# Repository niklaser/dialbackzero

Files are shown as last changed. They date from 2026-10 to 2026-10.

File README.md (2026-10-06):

# Dialback Zero

Dialback Zero lets an old computer get online through its serial port.
It works like a dial-up modem, but connects over Ethernet or Wi-Fi instead of
a phone line.

## Get started

1. [Assemble the board](docs/assembly.md) using the [parts list](docs/self-solder-parts.md).
2. [Print and assemble the enclosure](enclosure/README.md).
3. [Download the Raspberry Pi image](image/README.md) and write it to a microSD card.
4. [Connect your computer and make the first call](docs/setup.md).

Use a straight-through RS-232 cable and **38400 baud, 8N1, flow control off**.
The Rev C serial port supports TX, RX and GND.

| Connection | Dial number | Settings page |
|---|---|---|
| Internet | `2242525` | `http://172.16.0.1/`  |
| Private server | `777` | `http://172.16.77.1/` |

## Files and guides

- [PCB manufacturing files](manufacturing/rev-c/README.md)
- [Ready-to-print STL files](enclosure/README.md)
- [Software settings](software/README.md)
- [Private server with Docker Compose](server/README.md)
- [GPIO and connector reference](docs/hardware.md)
- [Licenses](LICENSES.md)

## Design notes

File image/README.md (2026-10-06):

# Raspberry Pi image

Raspberry Pi OS Lite 32-bit for Pi Zero, Zero W/WH and Zero 2 W, with
Dialback Zero preinstalled.

## Download from GitHub

1. Download an image from **Releases**, or open **Actions → Test and build
   Raspberry Pi image and update** and download the artifact from a successful run.
2. Extract the artifact ZIP if needed, then select the `.img.xz` in Raspberry
   Pi Imager using **Use custom**.
3. Set your user account, network and locale, then write the microSD card.
   Enable SSH in Imager if you want remote access.
4. Insert the card into the Pi and power it on. Continue with the
   [setup guide](../docs/setup.md).

After setup, use **Check for updates** and **Install update** on the settings
page. These update Dialback Zero software and preserve your settings; they do
not replace Raspberry Pi OS or require writing the card again.

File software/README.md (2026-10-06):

# Dialback Zero software

The modem, settings page, PPP and status lights start automatically at boot.
Use the [image guide](../image/README.md) and [first-boot guide](../docs/setup.md)
to get started. The optional [server](../server/README.md) provides the private
network reached by dialing `777`.

## Settings

Open `http://172.16.0.1/` over Internet PPP, `http://172.16.77.1/` over private
PPP, or `http://localhost/` on the Pi. Use `AT$CONFIG` for serial settings while
disconnected. The web page requires no JavaScript.

Settings take effect after a restart.

Speaker volume is 0–100% (default 70%); zero mutes it. `ATM1` enables dialing
sounds and `ATM0` disables them. Leave the board's MUTE jumper open for sound.
Configure Wi-Fi in Raspberry Pi Imager or on the settings page.

## Update

On the settings page, select **Check for updates**, then **Install update**.
Installation disconnects the current call; reconnect afterward and open settings
to see the result. Updates preserve your settings and update Dialback Zero
software only, not Raspberry Pi OS or the microSD image.

## Diagnostics

```sh
systemctl status dialback-zero.target dialback-zero-modem.service
journalctl -u dialback-zero-modem.service -b
sudo wg show wg-dbz latest-handshakes
```

See [LED meanings and GPIOs](../docs/hardware.md) and [licenses](../LICENSES.md).

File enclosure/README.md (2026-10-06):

# Enclosure

## Print

Download these files and import them into your slicer at **100% scale**:

| File | Quantity | Print orientation |
|---|---:|---|
| [Base](dialback-zero-base.stl) | 1 | Floor down |
| [Lid](dialback-zero-lid.stl) | 1 | Roof down |
| [Power-button cap](power-button-cap.stl) | 1 | On its flange |
| [12 mm Pi spacer](pi-spacer-12mm.stl) | 4 | Vertical |

Use **a 0.4 mm nozzle, 0.2 mm layers and four perimeters**.

Also needed: **two M3 x 25 screws** and
**two M3 hex nuts**.

## Assemble

1. Fit the Pi's male header on its component side and the board's J1 female
   socket on the underside. Use the sockets in the [parts list](../docs/self-solder-parts.md).
2. Place the Pi on the base guide pins. Slide a printed spacer onto each pin.
3. Align J1 with the Pi header and press the board down evenly onto its supports.
4. Insert the button cap from inside the lid with its flange wings vertical.
   Rotate it 90° so the power symbol is upright, and check it moves freely.
5. Slide the two nuts into the lid pockets. Lower the lid over the connectors,
   keeping the cap aligned with the power switch.
6. Insert both screws from below and tighten lightly until the case closes.

Remove both screws to open the case. The screws do not pass through either board.

STL files: **CC0-1.0**.

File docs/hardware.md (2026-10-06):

# Rev C hardware reference

The PCB is 130 × 80 mm. J1, the Pi socket, mounts underneath; all other parts
mount on top. See [assembly](assembly.md), [hand-soldered parts](self-solder-parts.md)
and [enclosure](../enclosure/README.md).

| Function | BCM GPIO | Physical header pin |
| --- | ---: | ---: |
| UART transmit to RS-232 driver | 14 | 8 |
| UART receive from RS-232 driver | 15 | 10 |
| Mono PWM audio | 12 | 32 |
| Reserved second audio output, not connected | 13 | 33 |
| Power-button interrupt, active low | 3 | 5 |
| Final shutdown power cut, active high | 26 | 37 |
| W5500 MOSI / MISO / clock / chip select | 10 / 9 / 11 / 8 | 19 / 21 / 23 / 24 |
| W5500 interrupt | 4 | 7 |
| MR / NET / SD / RD / CD / OH / AA lights | 23 / 25 / 22 / 27 / 24 / 5 / 6 | 16 / 22 / 15 / 13 / 18 / 29 / 31 |

PWR follows the switched 5 V rail. The other lights are active high: MR means
modem ready, NET means an upstream IPv4 address, SD/RD show data from/to the
computer, CD means connected, OH means off-hook and AA means auto-answer.

DE9 J2 uses pin 2 for RS-232 output, pin 3 for input and pin 5 for ground.
Other signal pins are unconnected; shield mounts are grounded.
Use a **straight-through cable with flow control off**.

The [hardware installer](../software/hardware/install.py) configures UART,
audio, shutdown and Ethernet. LED software must use only the listed LED GPIOs;
power, UART and Ethernet pins belong to kernel drivers.

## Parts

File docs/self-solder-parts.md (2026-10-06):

# Hand-soldered parts for Rev C

Buy 15 parts. **J1 mounts underneath** the carrier; all other parts mount on top.
USB-C J4 is factory fitted. Follow the [assembly guide](assembly.md).

| References | Qty | Part | Notes |
| --- | ---: | --- | --- |
| D1–D8 | 8 | Kingbright [WP934CB/GD](https://www.kingbrightusa.com/images/catalog/spec/wp934cb-gd.pdf) green or [WP934CB/YD](https://www.kingbrightusa.com/images/catalog/spec/wp934cb-yd.pdf) yellow | Right-angle LEDs; follow polarity markings |
| C17 | 1 | Panasonic EEU-FR1A221 | 220 µF, 10 V, 6.3 mm body, 2.5 mm lead pitch; follow polarity markings |
| J1 | 1 | [Samtec SSQ-120-01-G-D](https://suddendocs.samtec.com/catalog_english/ssq_th.pdf) or [Würth 61304021821](https://www.we-online.com/components/products/datasheet/61304021821.pdf) | Bottom-side 2 × 20 Pi socket |
| J2 | 1 | [Assmann A-DF 09 A/KG-T2S](https://www.assmann-wsw.com/uploads/pcn/PCN%2020120913-A-DX%20XX%20A_KG-T2_T4-rev0.pdf) or [Amphenol L77SDE09SA4CH4F48](https://cdn.amphenol-cs.com/media/wysiwyg/files/drawing/l77sdxxxsa4ch4f48.pdf) | Right-angle female DE9 with board locks and 4-40 hardware |
| J3 | 1 | Würth 61300211121 | 2.54 mm, 1 × 2 MUTE header |
| J5 | 1 | [Würth 7499010121A](https://www.we-online.com/components/products/datasheet/7499010121A.pdf) | Horizontal RJ45 with integrated magnetics |
| LS1 | 1 | [PUI Audio AST-02308MR-R](https://puiaudio.com/file/specs-AST-02308MR-R.pdf) | 8-ohm magnetic speaker, not a piezo sounder |
| SW1 | 1 | C&K PTS645VL39-2 LFS | Right-angle momentary power button |

A 2.54 mm jumper for J3 is optional: fitted mutes the speaker; open enables it.

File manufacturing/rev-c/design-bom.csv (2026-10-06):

Reference | Value | Footprint | MPN | Manufacturer | Datasheet | FactoryAssembly | Notes
J1 | Pi Zero / Zero 2 W | DialbackZero:PinSocket_Samtec_SSQ-120-01-G-D | SSQ-120-01-G-D | Samtec Inc. | https://www.samtec.com/products/ssq-120-01-g-d | no | USER SOLDER AFTER DELIVERY; DNP for factory assembly. Female socket on BOTTOM; Pi below carrier with component-side 2x20 2.54mm male header; Existing exact MPN. 2x20 female receptacle, 2.54 mm pitch; mounted on PCB bottom. Manufacturer product page contains print/catalog and footprint downloads.
U1 | MAX3232EIDR | DialbackZero:SOIC-16_3.9x9.9mm_P1.27mm | MAX3232EIDR | Texas Instruments | https://www.ti.com/lit/ds/symlink/max3232e.pdf | yes | ; Authorized replacement of obsolete MAX3232IDR; SOIC-16. C1-C4 remain 100 nF at 3.3 V; C5 changed to 2.2 uF. TI requires >=1 uF VCC bypass for stated IEC ESD ratings; assembly/device-level ESD validation still required.
J2 | A-DF 09 A/KG-T2S | DialbackZero:DSUB9_Assmann_A-DF09A_KG-T2S | A-DF 09 A/KG-T2S | Assmann WSW Components | https://www.assmann-wsw.com/uploads/datasheets/ASS_4888_CO.pdf | yes | ASSMANN female DE9 DCE, 2.77x2.84mm, grounded shell boardlocks; see mechanical.md; Authorized replacement of A-DF 09 A/KG-T2. Mechanical review confirmed same PCB geometry. Female right-angle DE9, 8.10 mm backset, board locks, 4-40 screwlocks. DigiKey AE10921-ND.
C1 | 100n | DialbackZero:C_0805_2012Metric_Pad1.18x1.45mm_HandSolder | CC0805KRX7R9BB104 | YAGEO | https://yageogroup.com/content/datasheet/asset/file/UPY-GPHC_X7R_6_3V-TO-250V | yes | X7R 16V; 0805, 0.1 uF, X7R, ±10%, 50 V. Capacitance value preserved; voltage rating meets or exceeds design requirement.
C2 | 100n | DialbackZero:C_0805_2012Metric_Pad1.18x1.45mm_HandSolder | CC0805KRX7R9BB104 | YAGEO | https://yageogroup.com/content/datasheet/asset/file/UPY-GPHC_X7R_6_3V-TO-250V | yes | X7R 16V; 0805, 0.1 uF, X7R, ±10%, 50 V. Capacitance value preserved; voltage rating meets or exceeds design requirement.
C3 | 100n | DialbackZero:C_0805_2012Metric_Pad1.18x1.45mm_HandSolder | CC0805KRX7R9BB104 | YAGEO | https://yageogroup.com/content/datasheet/asset/file/UPY-GPHC_X7R_6_3V-TO-250V | yes | X7R 16V; 0805, 0.1 uF, X7R, ±10%, 50 V. Capacitance value preserved; voltage rating meets or exceeds design requirement.
C4 | 100n | DialbackZero:C_0805_2012Metric_Pad1.18x1.45mm_HandSolder | CC0805KRX7R9BB104 | YAGEO | https://yageogroup.com/content/datasheet/asset/file/UPY-GPHC_X7R_6_3V-TO-250V | yes | X7R 16V; 0805, 0.1 uF, X7R, ±10%, 50 V. Capacitance value preserved; voltage rating meets or exceeds design requirement.
C5 | 2.2u | DialbackZero:C_0805_2012Metric_Pad1.18x1.45mm_HandSolder | GRM21BR71C225KA12L | Murata Electronics | https://search.murata.co.jp/Ceramy/image/img/A01X/G101/ENG/GRM21BR71C225KA12-01A.pdf | yes | X7R 16V; Authorized change from 100 nF to 2.2 uF for MAX3232EIDR VCC bypass. 0805 X7R ±10% 16 V. Current Murata reference sheet fetched 2026-09-22 is dated 2026-06-25. Murata typical DC-bias chart (2013-03-08 manufacturer document, Octopart mirror, page 2) was visually inspected: loss at 3.3 V is only a few percent, conservatively <10%, giving about 2.1 uF typical. Applying an illustrative 10% bias loss, -10% nominal tolerance and -15% temperature change gives 1.51 uF. This is engineering margin based on a typical curve, not a guaranteed minimum across aging/lot/temperature or IEC ESD certification.
R1 | 2.2k | DialbackZero:R_0805_2012Metric_Pad1.20x1.40mm_HandSolder | RC0805FR-072K2L | YAGEO | https://yageogroup.com/content/datasheet/asset/file/PYU-RC_GROUP_51_ROHS_L | yes | 0805, 1%, >=0.125W; 0805, 2200 ohm, ±1% tolerance, 0.125 W. Preserves circuit value.
D1 | PWR / WP934CB/GD | DialbackZero:LED_Kingbright_WP934CB_Horizontal | WP934CB/GD | Kingbright | https://www.kingbrightusa.com/images/catalog/spec/wp934cb-gd.pdf | yes | 3mm right-angle; housing flush to PCB; emission toward front; Existing exact MPN; 3 mm green right-angle LED housing and original mechanical footprint.
R2 | 1k | DialbackZero:R_0805_2012Metric_Pad1.20x1.40mm_HandSolder | RC0805FR-071KL | YAGEO | https://yageogroup.com/content/datasheet/asset/file/PYU-RC_GROUP_51_ROHS_L | yes | 0805, 1%, >=0.125W; 0805, 1000 ohm, ±1% tolerance, 0.125 W. Preserves circuit value.
D2 | MR / WP934CB/GD | DialbackZero:LED_Kingbright_WP934CB_Horizontal | WP934CB/GD | Kingbright | https://www.kingbrightusa.com/images/catalog/spec/wp934cb-gd.pdf | yes | 3mm right-angle; housing flush to PCB; emission toward front; Existing exact MPN; 3 mm green right-angle LED housing and original mechanical footprint.
R11 | 1k | DialbackZero:R_0805_2012Metric_Pad1.20x1.40mm_HandSolder | RC0805FR-071KL | YAGEO | https://yageogroup.com/content/datasheet/asset/file/PYU-RC_GROUP_51_ROHS_L | yes | 0805, 1%, >=0.125W; 0805, 1000 ohm, ±1% tolerance, 0.125 W. Preserves circuit value.
D3 | NET / WP934CB/GD | DialbackZero:LED_Kingbright_WP934CB_Horizontal | WP934CB/GD | Kingbright | https://www.kingbrightusa.com/images/catalog/spec/wp934cb-gd.pdf | yes | 3mm right-angle; housing flush to PCB; emission toward front; Existing exact MPN; 3 mm green right-angle LED housing and original mechanical footprint.
R12 | 1k | DialbackZero:R_0805_2012Metric_Pad1.20x1.40mm_HandSolder | RC0805FR-071KL | YAGEO | https://yageogroup.com/content/datasheet/asset/file/PYU-RC_GROUP_51_ROHS_L | yes | 0805, 1%, >=0.125W; 0805, 1000 ohm, ±1% tolerance, 0.125 W. Preserves circuit value.
D4 | SD / WP934CB/GD | DialbackZero:LED_Kingbright_WP934CB_Horizontal | WP934CB/GD | Kingbright | https://www.kingbrightusa.com/images/catalog/spec/wp934cb-gd.pdf | yes | 3mm right-angle; housing flush to PCB; emission toward front; Existing exact MPN; 3 mm green right-angle LED housing and original mechanical footprint.
R13 | 1k | DialbackZero:R_0805_2012Metric_Pad1.20x1.40mm_HandSolder | RC0805FR-071KL | YAGEO | https://yageogroup.com/content/datasheet/asset/file/PYU-RC_GROUP_51_ROHS_L | yes | 0805, 1%, >=0.125W; 0805, 1000 ohm, ±1% tolerance, 0.125 W. Preserves circuit value.
D5 | RD / WP934CB/GD | DialbackZero:LED_Kingbright_WP934CB_Horizontal | WP934CB/GD | Kingbright | https://www.kingbrightusa.com/images/catalog/spec/wp934cb-gd.pdf | yes | 3mm right-angle; housing flush to PCB; emission toward front; Existing exact MPN; 3 mm green right-angle LED housing and original mechanical footprint.
R14 | 1k | DialbackZero:R_0805_2012Metric_Pad1.20x1.40mm_HandSolder | RC0805FR-071KL | YAGEO | https://yageogroup.com/content/datasheet/asset/file/PYU-RC_GROUP_51_ROHS_L | yes | 0805, 1%, >=0.125W; 0805, 1000 ohm, ±1% tolerance, 0.125 W. Preserves circuit value.
D6 | CD / WP934CB/GD | DialbackZero:LED_Kingbright_WP934CB_Horizontal | WP934CB/GD | Kingbright | https://www.kingbrightusa.com/images/catalog/spec/wp934cb-gd.pdf | yes | 3mm right-angle; housing flush to PCB; emission toward front; Existing exact MPN; 3 mm green right-angle LED housing and original mechanical footprint.
R15 | 1k | DialbackZero:R_0805_2012Metric_Pad1.20x1.40mm_HandSolder | RC0805FR-071KL | YAGEO | https://yageogroup.com/content/datasheet/asset/file/PYU-RC_GROUP_51_ROHS_L | yes | 0805, 1%, >=0.125W; 0805, 1000 ohm, ±1% tolerance, 0.125 W. Preserves circuit value.
D7 | OH / WP934CB/GD | DialbackZero:LED_Kingbright_WP934CB_Horizontal | WP934CB/GD | Kingbright | https://www.kingbrightusa.com/images/catalog/spec/wp934cb-gd.pdf | yes | 3mm right-angle; housing flush to PCB; emission toward front; Existing exact MPN; 3 mm green right-angle LED housing and original mechanical footprint.
R16 | 1k | DialbackZero:R_0805_2012Metric_Pad1.20x1.40mm_HandSolder | RC0805FR-071KL | YAGEO | https://yageogroup.com/content/datasheet/asset/file/PYU-RC_GROUP_51_ROHS_L | yes | 0805, 1%, >=0.125W; 0805, 1000 ohm, ±1% tolerance, 0.125 W. Preserves circuit value.
D8 | AA / WP934CB/GD | DialbackZero:LED_Kingbright_WP934CB_Horizontal | WP934CB/GD | Kingbright | https://www.kingbrightusa.com/images/catalog/spec/wp934cb-gd.pdf | yes | 3mm right-angle; housing flush to PCB; emission toward front; Existing exact MPN; 3 mm green right-angle LED housing and original mechanical footprint.
J4 | USB4125-GF-A-0190 | DialbackZero:USB_C_Receptacle_GCT_USB4125-xx-x-0190_6P_TopMnt_Horizontal | USB4125-GF-A-0190 | GCT | https://gct.co/files/drawings/usb4125.pdf | yes | 5V/3A supply required; power only; Pi PWR IN internal; Existing exact MPN. USB-C power connector; LCSC minimum 1. Do not replace with visually similar USB-C footprint.
R17 | 5.1k | DialbackZero:R_0805_2012Metric_Pad1.20x1.40mm_HandSolder | RC0805FR-075K1L | YAGEO | https://yageogroup.com/content/datasheet/asset/file/PYU-RC_GROUP_51_ROHS_L | yes | 0805, 1%, >=0.125W; 0805, 5100 ohm, ±1% tolerance, 0.125 W. Preserves circuit value. Mouser Canada snapshot last week reported 44,735; this is the same exact MPN, not a replacement.
R18 | 5.1k | DialbackZero:R_0805_2012Metric_Pad1.20x1.40mm_HandSolder | RC0805FR-075K1L | YAGEO | https://yageogroup.com/content/datasheet/asset/file/PYU-RC_GROUP_51_ROHS_L | yes | 0805, 1%, >=0.125W; 0805, 5100 ohm, ±1% tolerance, 0.125 W. Preserves circuit value. Mouser Canada snapshot last week reported 44,735; this is the same exact MPN, not a replacement.
U3 | TPS259470LRPWR | DialbackZero:TPS259470_RPW_2x2mm | TPS259470LRPWR | Texas Instruments | https://www.ti.com/lit/ds/symlink/tps25947.pdf | yes | Latch-off eFuse, always-on reverse blocking; 2.33A nominal limit; Existing exact MPN; eFuse, 10-VQFN-HR 2x2 mm. Preserve L latch variant.
R19 | 26.1k | DialbackZero:R_0805_2012Metric_Pad1.20x1.40mm_HandSolder | RC0805FR-0726K1L | YAGEO | https://yageogroup.com/content/datasheet/asset/file/PYU-RC_GROUP_51_ROHS_L | yes | 1% UVLO upper; 0805, 26100 ohm, ±1% tolerance, 0.125 W. Preserves circuit value.
R20 | 10k | DialbackZero:R_0805_2012Metric_Pad1.20x1.40mm_HandSolder | RC0805FR-0710KL | YAGEO | https://yageogroup.com/content/datasheet/asset/file/PYU-RC_GROUP_51_ROHS_L | yes | 1% UVLO lower; 0805, 10000 ohm, ±1% tolerance, 0.125 W. Preserves circuit value.
R21 | 34.8k | DialbackZero:R_0805_2012Metric_Pad1.20x1.40mm_HandSolder | RT0805BRD0734K8L | YAGEO | https://yageogroup.com/content/datasheet/asset/file/PYU-RT_1-TO-0-01_ROHS_L | yes | 0.1% OVLO upper; do not substitute 1%; 0805, 34800 ohm, ±0.1% tolerance, 0.125 W. Required 0.1% eFuse threshold divider part; do not substitute 1%.
R22 | 10k | DialbackZero:R_0805_2012Metric_Pad1.20x1.40mm_HandSolder | RT0805BRD0710KL | YAGEO | https://yageogroup.com/content/datasheet/asset/file/PYU-RT_1-TO-0-01_ROHS_L | yes | 0.1% OVLO lower; do not substitute 1%; 0805, 10000 ohm, ±0.1% tolerance, 0.125 W. Required 0.1% eFuse threshold divider part; do not substitute 1%.
R23 | 1.43k | DialbackZero:R_0805_2012Metric_Pad1.20x1.40mm_HandSolder | RC0805FR-071K43L | YAGEO | https://yageogroup.com/content/datasheet/asset/file/PYU-RC_GROUP_51_ROHS_L | yes | 1% current limit; 2.33A nominal; 0805, 1430 ohm, ±1% tolerance, 0.125 W. Preserves circuit value.
C19 | 1u | DialbackZero:C_0805_2012Metric_Pad1.18x1.45mm_HandSolder | CC0805KKX7R9BB105 | YAGEO | https://yageogroup.com/content/datasheet/asset/file/UPY-GPHC_X7R_6_3V-TO-250V | yes | X7R 50V input bypass; 0805, 1 uF, X7R, ±10%, 50 V. Capacitance value preserved; voltage rating meets or exceeds design requirement.
C20 | 100n | DialbackZero:C_0805_2012Metric_Pad1.18x1.45mm_HandSolder | CC0805KRX7R9BB104 | YAGEO | https://yageogroup.com/content/datasheet/asset/file/UPY-GPHC_X7R_6_3V-TO-250V | yes | X7R 50V; place close to U3 IN/GND; 0805, 0.1 uF, X7R, ±10%, 50 V. Capacitance value preserved; voltage rating meets or exceeds design requirement.
C21 | 10n | DialbackZero:C_0805_2012Metric_Pad1.18x1.45mm_HandSolder | CC0805KRX7R9BB103 | YAGEO | https://yageogroup.com/content/datasheet/asset/file/UPY-GPHC_X7R_6_3V-TO-250V | yes | X7R 50V soft start about 25ms; 0805, 0.01 uF, X7R, ±10%, 50 V. Capacitance value preserved; voltage rating meets or exceeds design requirement.
C22 | 10u | DialbackZero:C_0805_2012Metric_RevB_C22 | CC0805KKX7R6BB106 | YAGEO | https://yageogroup.com/content/datasheet/asset/file/UPY-GPHC_X7R_6_3V-TO-250V | yes | X7R 10V output bypass; 0805, 10 uF, X7R, ±10%, 10 V. Capacitance value preserved; voltage rating meets or exceeds design requirement. Existing exact MPN preserved. LCSC minimum/multiple 5. DigiKey snapshot showed no stock; do not use its obsolete cached availability as evidence.
D9 | SMAJ12A | DialbackZero:D_SMA | SMAJ12A | Littelfuse Inc. | https://www.littelfuse.com/assetdocs/tvs-diodes-smaj-datasheet?assetguid=13c2a823-03b8-4d1f-9ddc-9b44670aed9d | yes | Unidirectional 12V standoff TVS; pad1 cathode upstream of eFuse; Manufacturer is explicitly Littelfuse, not an unspecified SMAJ12A equivalent. Unidirectional 12 V standoff TVS, SMA/DO-214AC, 400 W.
U2 | PAM8406DR | DialbackZero:SOIC16_RevB_U2 | PAM8406DR | Diodes Incorporated | https://www.diodes.com/datasheet/download/PAM8406.pdf | yes | ; Existing exact MPN; SOP-16 audio amplifier, mono design uses one channel.
R3 | 1k | DialbackZero:R_0805_2012Metric_Pad1.20x1.40mm_HandSolder | RC0805FR-071KL | YAGEO | https://yageogroup.com/content/datasheet/asset/file/PYU-RC_GROUP_51_ROHS_L | yes | 0805, 1%, >=0.125W; 0805, 1000 ohm, ±1% tolerance, 0.125 W. Preserves circuit value.
C6 | 10n | DialbackZero:C_0805_2012Metric_Pad1.18x1.45mm_HandSolder | CC0805KRX7R9BB103 | YAGEO | https://yageogroup.com/content/datasheet/asset/file/UPY-GPHC_X7R_6_3V-TO-250V | yes | X7R 16V; 0805, 0.01 uF, X7R, ±10%, 50 V. Capacitance value preserved; voltage rating meets or exceeds design requirement.
R4 | 47k | DialbackZero:R_0805_2012Metric_Pad1.20x1.40mm_HandSolder | RC0805FR-0747KL | YAGEO | https://yageogroup.com/content/datasheet/asset/file/PYU-RC_GROUP_51_ROHS_L | yes | 0805, 1%, >=0.125W; 0805, 47000 ohm, ±1% tolerance, 0.125 W. Preserves circuit value.
R5 | 1k | DialbackZero:R_0805_2012Metric_Pad1.20x1.40mm_HandSolder | RC0805FR-071KL | YAGEO | https://yageogroup.com/content/datasheet/asset/file/PYU-RC_GROUP_51_ROHS_L | yes | 0805, 1%, >=0.125W; 0805, 1000 ohm, ±1% tolerance, 0.125 W. Preserves circuit value.
C7 | 22n | DialbackZero:C_0805_2012Metric_Pad1.18x1.45mm_HandSolder | CC0805KRX7R9BB223 | YAGEO | https://yageogroup.com/content/datasheet/asset/file/UPY-GPHC_X7R_6_3V-TO-250V | yes | X7R 16V; 0805, 0.022 uF, X7R, ±10%, 50 V. Capacitance value preserved; voltage rating meets or exceeds design requirement.
C8 | 470n | DialbackZero:C_0805_2012Metric_RevB_C8 | CC0805KKX7R9BB474 | YAGEO | https://yageogroup.com/content/datasheet/asset/file/UPY-GPHC_X7R_6_3V-TO-250V | yes | X7R 16V; 0805, 0.47 uF, X7R, ±10%, 50 V. Capacitance value preserved; voltage rating meets or exceeds design requirement.
F1 | 0.75A PTC | DialbackZero:Fuse_Littelfuse_MINISMDC075F-2 | MINISMDC075F-2 | Littelfuse Inc. | https://www.littelfuse.com/assetdocs/ptc-minismdc075f-2-product-specification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 | yes | Littelfuse MINISMDC075F-2, amplifier branch only; Authorized replacement of NRND Bourns MF-MSMF075-2. Active 1812 PPTC, 13.2 V, hold 0.75 A, trip 1.5 A, fault current 100 A, max 0.2 s trip at 8 A/20 C, resistance 0.11..0.45 ohm. Body max 4.73 x 3.41 x 0.62 mm. Manufacturer recommended pads: 1.68 x 3.15 mm, 3.10 mm inner gap, centers ±2.39 mm. Root applies pad change; not a blind drop-in substitution. Thermal derating and reflow still require prototype validation.
R9 | 10R | DialbackZero:R_0805_2012Metric_RevB_R9 | RC0805FR-0710RL | YAGEO | https://yageogroup.com/content/datasheet/asset/file/PYU-RC_GROUP_51_ROHS_L | yes | 0805, 1%, >=0.125W; 0805, 10 ohm, ±1% tolerance, 0.125 W. Preserves circuit value.
R10 | 47k | DialbackZero:R_0805_2012Metric_Pad1.20x1.40mm_HandSolder | RC0805FR-0747KL | YAGEO | https://yageogroup.com/content/datasheet/asset/file/PYU-RC_GROUP_51_ROHS_L | yes | 0805, 1%, >=0.125W; 0805, 47000 ohm, ±1% tolerance, 0.125 W. Preserves circuit value.
C12 | 1u | DialbackZero:C_0805_2012Metric_Pad1.18x1.45mm_HandSolder | CC0805KKX7R9BB105 | YAGEO | https://yageogroup.com/content/datasheet/asset/file/UPY-GPHC_X7R_6_3V-TO-250V | yes | X7R 16V; 0805, 1 uF, X7R, ±10%, 50 V. Capacitance value preserved; voltage rating meets or exceeds design requirement.
C13 | 1u | DialbackZero:C_0805_2012Metric_Pad1.18x1.45mm_HandSolder | CC0805KKX7R9BB105 | YAGEO | https://yageogroup.com/content/datasheet/asset/file/UPY-GPHC_X7R_6_3V-TO-250V | yes | X7R 16V; 0805, 1 uF, X7R, ±10%, 50 V. Capacitance value preserved; voltage rating meets or exceeds design requirement.
C14 | 1u | DialbackZero:C_0805_2012Metric_RevB_C14 | CC0805KKX7R9BB105 | YAGEO | https://yageogroup.com/content/datasheet/asset/file/UPY-GPHC_X7R_6_3V-TO-250V | yes | X7R 16V; 0805, 1 uF, X7R, ±10%, 50 V. Capacitance value preserved; voltage rating meets or exceeds design requirement.
C15 | 1u | DialbackZero:C_0805_2012Metric_Pad1.18x1.45mm_HandSolder | CC0805KKX7R9BB105 | YAGEO | https://yageogroup.com/content/datasheet/asset/file/UPY-GPHC_X7R_6_3V-TO-250V | yes | X7R 16V; 0805, 1 uF, X7R, ±10%, 50 V. Capacitance value preserved; voltage rating meets or exceeds design requirement.
C16 | 100n | DialbackZero:C_0805_2012Metric_Pad1.18x1.45mm_HandSolder | CC0805KRX7R9BB104 | YAGEO | https://yageogroup.com/content/datasheet/asset/file/UPY-GPHC_X7R_6_3V-TO-250V | yes | X7R 16V; 0805, 0.1 uF, X7R, ±10%, 50 V. Capacitance value preserved; voltage rating meets or exceeds design requirement.
C17 | 220u 10V | DialbackZero:CP_Panasonic_EEUFR1A221_D6.3_P2.50 | EEU-FR1A221 | Panasonic Industry | https://industrial.panasonic.com/cdbs/www-data/pdf/RDF0000/ABA0000C1259.pdf | yes | ; 220 uF ±20%, 10 V, radial, diameter 6.3 mm, lead pitch 2.5 mm. Nominal body 11.2 mm; DigiKey maximum seated height 12.7 mm (<16 mm enclosure allowance). Manufacturer spelling EEUFR1A221 denotes same part; distributor MPN uses hyphen. Polarized.
C18 | 100n | DialbackZero:C_0805_2012Metric_Pad1.18x1.45mm_HandSolder | CC0805KRX7R9BB104 | YAGEO | https://yageogroup.com/content/datasheet/asset/file/UPY-GPHC_X7R_6_3V-TO-250V | yes | X7R 16V; 0805, 0.1 uF, X7R, ±10%, 50 V. Capacitance value preserved; voltage rating meets or exceeds design requirement.
J3 | MUTE jumper | DialbackZero:PinHeader_Wurth_61300211121 | 61300211121 | Würth Elektronik | https://www.we-online.com/components/products/datasheet/61300211121.pdf | yes | Close to mute speaker; normally open; WR-PHD 1x02 vertical male header, 2.54 mm pitch; body 5.08 x 2.54 x 2.54 mm; mating length 6.0 ±0.2 mm, solder tail 3.0 ±0.2 mm. Pin 0.64 ±0.15 mm square; recommended PCB hole 1.10 ±0.15 mm. Optional loose shunt is listed separately and normally left off (shunt mutes).
LS1 | AST-02308MR-R / 8R | DialbackZero:Speaker_PUI_AST-02308MR-R | AST-02308MR-R | PUI Audio, Inc. | https://puiaudio.com/file/specs-AST-02308MR-R.pdf | yes | Passive PCB speaker 23mm, 0.1W, pin pitch10mm; Existing exact MPN; 8 ohm PCB speaker, 23 mm body, 8.5 mm nominal height.
C11 | 470n | DialbackZero:C_0805_2012Metric_Pad1.18x1.45mm_HandSolder | CC0805KKX7R9BB474 | YAGEO | https://yageogroup.com/content/datasheet/asset/file/UPY-GPHC_X7R_6_3V-TO-250V | yes | X7R 16V; 0805, 0.47 uF, X7R, ±10%, 50 V. Capacitance value preserved; voltage rating meets or exceeds design requirement.
U4 | LTC2954ITS8-1#TRPBF | DialbackZero:LTC2954_TS8 | LTC2954ITS8-1#TRPBF | Analog Devices Inc. | https://www.analog.com/media/en/technical-documentation/data-sheets/2954fb.pdf | yes | Always powered; active-high open-drain enable; short press IRQ, held press forced off; Existing exact MPN; TSOT-23-8, active-high EN -1 variant. Preserve #TRPBF suffix in MPN (URL omits #).
Q1 | MMBT3904LT1G | DialbackZero:SOT-23 | MMBT3904LT1G | onsemi | https://www.onsemi.com/pdf/datasheet/mmbt3904lt1-d.pdf | yes | GPIO26 HIGH pulls KILL low; base pulldown keeps boot/reboot safe; Existing exact MPN; NPN SOT-23. Mouser indexed stock evidence; DigiKey opened page showed zero stock, so do not rely on older DigiKey search counts.
R24 | 330k | DialbackZero:R_0805_2012Metric_Pad1.20x1.40mm_HandSolder | RC0805FR-07330KL | YAGEO | https://yageogroup.com/content/datasheet/asset/file/PYU-RC_GROUP_51_ROHS_L | yes | 1% KILL upper divider; protects KILL from raw input excursions; 0805, 330000 ohm, ±1% tolerance, 0.125 W. Preserves circuit value.
R25 | 100k | DialbackZero:R_0805_2012Metric_Pad1.20x1.40mm_HandSolder | RC0805FR-07100KL | YAGEO | https://yageogroup.com/content/datasheet/asset/file/PYU-RC_GROUP_51_ROHS_L | yes | 1% KILL lower divider; keep KILL high throughout Linux boot; 0805, 100000 ohm, ±1% tolerance, 0.125 W. Preserves circuit value.
R26 | 10k | DialbackZero:R_0805_2012Metric_Pad1.20x1.40mm_HandSolder | RC0805FR-0710KL | YAGEO | https://yageogroup.com/content/datasheet/asset/file/PYU-RC_GROUP_51_ROHS_L | yes | 1% NPN base resistor; final poweroff GPIO only; 0805, 10000 ohm, ±1% tolerance, 0.125 W. Preserves circuit value.
R27 | 100k | DialbackZero:R_0805_2012Metric_Pad1.20x1.40mm_HandSolder | RC0805FR-07100KL | YAGEO | https://yageogroup.com/content/datasheet/asset/file/PYU-RC_GROUP_51_ROHS_L | yes | 1% hardware base pulldown; 0805, 100000 ohm, ±1% tolerance, 0.125 W. Preserves circuit value.
R28 | 10k | DialbackZero:R_0805_2012Metric_Pad1.20x1.40mm_HandSolder | RC0805FR-0710KL | YAGEO | https://yageogroup.com/content/datasheet/asset/file/PYU-RC_GROUP_51_ROHS_L | yes | 1% INT pullup to switched Pi 3V3 only; never raw5V; 0805, 10000 ohm, ±1% tolerance, 0.125 W. Preserves circuit value.
R29 | 2.2k | DialbackZero:R_0805_2012Metric_Pad1.20x1.40mm_HandSolder | RC0805FR-072K2L | YAGEO | https://yageogroup.com/content/datasheet/asset/file/PYU-RC_GROUP_51_ROHS_L | yes | Output discharge bleeder, 0805 >=0.125W; 0805, 2200 ohm, ±1% tolerance, 0.125 W. Preserves circuit value.
C23 | 100n | DialbackZero:C_0805_2012Metric_Pad1.18x1.45mm_HandSolder | CC0805KRX7R9BB104 | YAGEO | https://yageogroup.com/content/datasheet/asset/file/UPY-GPHC_X7R_6_3V-TO-250V | yes | Always-on controller bypass, X7R 50V; 0805, 0.1 uF, X7R, ±10%, 50 V. Capacitance value preserved; voltage rating meets or exceeds design requirement.
C24 | 1.5u | DialbackZero:C_0805_2012Metric_Pad1.18x1.45mm_HandSolder | CGA4J3X7R1E155K125AB | TDK Corporation | https://product.tdk.com/en/search/capacitor/ceramic/mlcc/info?part_no=CGA4J3X7R1E155K125AB | yes | PDT force-off timer: about 9.7s nominal continuous press; X7R 25V 10%, timer/temperature/bias tolerances additional; Existing exact MPN preserved: 1.5 uF, ±10%, 25 V, X7R, 0805. Power-button hard-off timer.
SW1 | PTS645VL39-2 LFS | DialbackZero:SW_CK_PTS645VL39-2LFS_Horizontal | PTS645VL39-2 LFS | C&K | https://www.ckswitches.com/media/1471/pts645.pdf | yes | Momentary normally open; front panel guided actuator; about10s hold forces power cut; Existing exact MPN; side-actuated tactile pushbutton. Preserve space before LFS.
U5 | W5500 | DialbackZero:LQFP-48_7x7mm_P0.5mm_RevC_U5 | W5500 | WIZnet | https://docs.wiznet.io/img/products/w5500/W5500_ds_v110e.pdf | yes | SPI0 CE0; Linux MACRAW Ethernet; 25 MHz oscillator; PMODE 111 autonegotiation; pin 23 grounded; 48-pin LQFP, 7 × 7 mm; SPI Ethernet controller.
U6 | TLV76733DGNR | DialbackZero:HVSSOP8_TLV76733_DGN_RevC_U6 | TLV76733DGNR | Texas Instruments | https://www.ti.com/lit/ds/symlink/tlv767.pdf | yes | 1 A / 3.3 V regulator with soldered ground thermal pad; switched 5 V feed; Fixed 3.3 V, 1 A LDO; HVSSOP-8 exposed thermal pad must be soldered to ground.
U7 | TPS3839G33DBZR | DialbackZero:SOT-23_RevC_U7 | TPS3839G33DBZR | Texas Instruments | https://www.ti.com/lit/ds/symlink/tps3839.pdf | yes | 3.08 V threshold, push-pull reset;120 ms minimum power-up delay; 3.08 V nominal reset threshold; 120 ms minimum reset release delay.
J5 | 7499010121A | DialbackZero:RJ45_Wuerth_7499010121A_Horizontal_RevC_J5 | 7499010121A | Würth Elektronik | https://www.we-online.com/components/products/datasheet/7499010121A.pdf | yes | 10/100BASE-T, separate center taps; green link/yellow activity LEDs; RXCT unconnected; no PoE; Independent TX/RX center taps; 100BASE-TX; no PoE.
Y1 | 25 MHz / 3.3 V / 25 ppm | DialbackZero:Oscillator_SMD_Abracon_ASE-4Pin_3.2x2.5mm_RevC_Y1 | ASE-25.000MHZ-L-R-T | Abracon | https://abracon.com/Oscillators/ASEseries.pdf | yes | 25 MHz CMOS oscillator, 25 ppm stability; XI external clock, XO unconnected; 25 MHz; 3.3 V CMOS; ±25 ppm overall stability; −40 to +85 °C; 2 ms maximum startup; 13 mA maximum supply current
FB1 | 120R@100MHz | DialbackZero:R_0805_2012Metric_RevC_FB1 | BLM21PG121SN1D | Murata | https://www.murata.com/products/productdata/8796738977822/ENFA0005.pdf | yes | Murata 120 Ω ferrite at 100 MHz, 3 A rating, 0.03 Ω maximum DC resistance; 120 Ω at 100 MHz; 3 A rated current; 0.03 Ω maximum DC resistance.
R30 | 12.4k | DialbackZero:R_0805_2012Metric_Pad1.20x1.40mm_HandSolder_RevC_R30 | RC0805FR-0712K4L | YAGEO | https://yageogroup.com/content/datasheet/asset/file/PYu-RC_GROUP_51_ROHS | yes | W5500 bias resistor, 1%; W5500 reference resistor; 12.4 kΩ, 1%, 0805, 0.125 W.
R31 | 49.9R | DialbackZero:R_0805_2012Metric_Pad1.20x1.40mm_HandSolder_RevC_R31 | RC0805FR-0749R9L | YAGEO | https://yageogroup.com/content/datasheet/asset/file/PYu-RC_GROUP_51_ROHS | yes | TX termination, 1%; Transmit termination; 49.9 Ω, 1%, 0805, 0.125 W.
R32 | 49.9R | DialbackZero:R_0805_2012Metric_Pad1.20x1.40mm_HandSolder_RevC_R32 | RC0805FR-0749R9L | YAGEO | https://yageogroup.com/content/datasheet/asset/file/PYu-RC_GROUP_51_ROHS | yes | TX termination, 1%; Transmit termination; 49.9 Ω, 1%, 0805, 0.125 W.
R33 | 10R | DialbackZero:R_0805_2012Metric_Pad1.20x1.40mm_HandSolder_RevC_R33 | RC0805FR-0710RL | YAGEO | https://yageogroup.com/content/datasheet/asset/file/PYu-RC_GROUP_51_ROHS | yes | TX center-tap feed; Transmit center-tap supply resistor; 10 Ω, 1%, 0805, 0.125 W.
R34 | 49.9R | DialbackZero:R_0805_2012Metric_Pad1.20x1.40mm_HandSolder_RevC_R34 | RC0805FR-0749R9L | YAGEO | https://yageogroup.com/content/datasheet/asset/file/PYu-RC_GROUP_51_ROHS | yes | RX termination, 1%; Receive termination; 49.9 Ω, 1%, 0805, 0.125 W.
R35 | 49.9R | DialbackZero:R_0805_2012Metric_Pad1.20x1.40mm_HandSolder_RevC_R35 | RC0805FR-0749R9L | YAGEO | https://yageogroup.com/content/datasheet/asset/file/PYu-RC_GROUP_51_ROHS | yes | RX termination, 1%; Receive termination; 49.9 Ω, 1%, 0805, 0.125 W.
R36 | 330R | DialbackZero:R_0805_2012Metric_Pad1.20x1.40mm_HandSolder_RevC_R36 | RC0805FR-07330RL | YAGEO | https://yageogroup.com/content/datasheet/asset/file/PYu-RC_GROUP_51_ROHS | yes | Magjack green LED current limit; Green RJ45 link indicator current limit; 330 Ω, 1%, 0805, 0.125 W.
R37 | 330R | DialbackZero:R_0805_2012Metric_Pad1.20x1.40mm_HandSolder_RevC_R37 | RC0805FR-07330RL | YAGEO | https://yageogroup.com/content/datasheet/asset/file/PYu-RC_GROUP_51_ROHS | yes | Magjack yellow LED current limit; Yellow RJ45 activity indicator current limit; 330 Ω, 1%, 0805, 0.125 W.
R40 | 10k | DialbackZero:R_0805_2012Metric_Pad1.20x1.40mm_HandSolder_RevC_R40 | RC0805FR-0710KL | YAGEO | https://yageogroup.com/content/datasheet/asset/file/PYu-RC_GROUP_51_ROHS | yes | SPI chip-select pull-up; SPI chip-select pull-up; 10 kΩ, 1%, 0805, 0.125 W.
R41 | 10k | DialbackZero:R_0805_2012Metric_Pad1.20x1.40mm_HandSolder_RevC_R41 | RC0805FR-0710KL | YAGEO | https://yageogroup.com/content/datasheet/asset/file/PYu-RC_GROUP_51_ROHS | yes | All three PHY mode pins pulled high; 111 selects autonegotiation; Pull all three PHY mode pins high for autonegotiation; 10 kΩ, 1%, 0805, 0.125 W.
C25 | 10u | DialbackZero:C_0805_2012Metric_Pad1.18x1.45mm_HandSolder_RevC_C25 | CC0805KKX7R6BB106 | YAGEO | https://yageogroup.com/content/datasheet/asset/file/UPY-GPHC_X7R_6_3V-TO-250V | yes | Ethernet capacitor; LDO input bypass; 10 µF, 10 V, X7R, 0805.
C26 | 10u | DialbackZero:C_0805_2012Metric_Pad1.18x1.45mm_HandSolder_RevC_C26 | CC0805KKX7R6BB106 | YAGEO | https://yageogroup.com/content/datasheet/asset/file/UPY-GPHC_X7R_6_3V-TO-250V | yes | Ethernet capacitor; LDO output bypass; 10 µF, 10 V, X7R, 0805.
C27 | 100n | DialbackZero:C_0805_2012Metric_Pad1.18x1.45mm_HandSolder_RevC_C27 | CC0805KRX7R9BB104 | YAGEO | https://yageogroup.com/content/datasheet/asset/file/UPY-GPHC_X7R_6_3V-TO-250V | yes | Ethernet capacitor; Local supply bypass; 100 nF, 50 V, X7R, 0805.
C28 | 100n | DialbackZero:C_0603_1608Metric_RevC_C28 | CC0603KRX7R9BB104 | YAGEO | https://www.yageogroup.com/download/specsheet/CC0603KRX7R9BB104 | yes | Ethernet capacitor; Local supply bypass; 100 nF, 50 V, X7R, 0603.; F.Cu local bypass for single-side factory assembly.
C29 | 100n | DialbackZero:C_0603_1608Metric_RevC_C29 | CC0603KRX7R9BB104 | YAGEO | https://www.yageogroup.com/download/specsheet/CC0603KRX7R9BB104 | yes | Ethernet capacitor; Local supply bypass; 100 nF, 50 V, X7R, 0603.; F.Cu local bypass for single-side factory assembly.
C30 | 100n | DialbackZero:C_0603_1608Metric_RevC_C30 | CC0603KRX7R9BB104 | YAGEO | https://www.yageogroup.com/download/specsheet/CC0603KRX7R9BB104 | yes | Ethernet capacitor; Local supply bypass; 100 nF, 50 V, X7R, 0603.; F.Cu local bypass for single-side factory assembly.
C31 | 100n | DialbackZero:C_0603_1608Metric_RevC_C31 | CC0603KRX7R9BB104 | YAGEO | https://www.yageogroup.com/download/specsheet/CC0603KRX7R9BB104 | yes | Ethernet capacitor; Local supply bypass; 100 nF, 50 V, X7R, 0603.; F.Cu local bypass for single-side factory assembly.
C32 | 100n | DialbackZero:C_0603_1608Metric_RevC_C32 | CC0603KRX7R9BB104 | YAGEO | https://www.yageogroup.com/download/specsheet/CC0603KRX7R9BB104 | yes | Ethernet capacitor; Local supply bypass; 100 nF, 50 V, X7R, 0603.; F.Cu local bypass for single-side factory assembly.
C33 | 100n | DialbackZero:C_0603_1608Metric_RevC_C33 | CC0603KRX7R9BB104 | YAGEO | https://www.yageogroup.com/download/specsheet/CC0603KRX7R9BB104 | yes | Ethernet capacitor; Local supply bypass; 100 nF, 50 V, X7R, 0603.; F.Cu local bypass for single-side factory assembly.
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

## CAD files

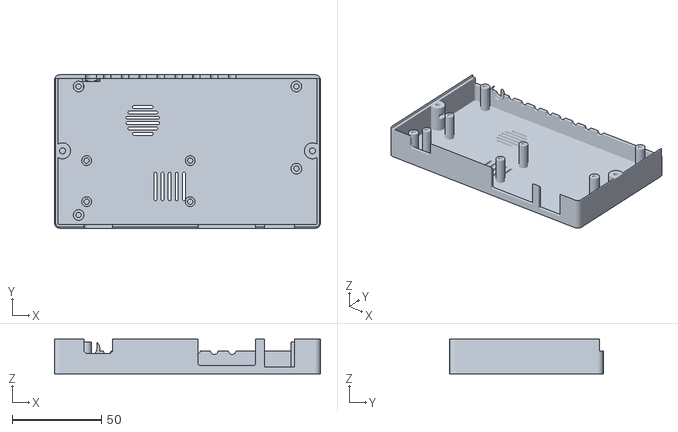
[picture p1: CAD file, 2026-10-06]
enclosure/dialback-zero-lid.stl
149.0 x 86.0 x 19.4

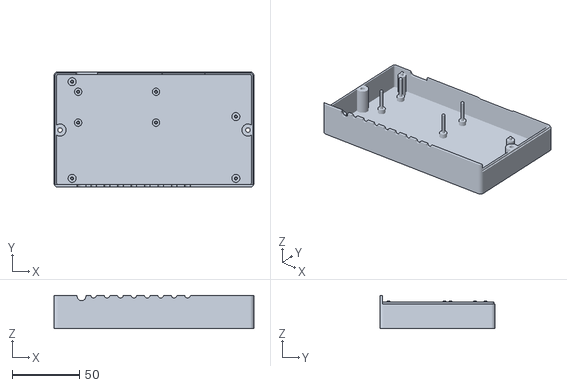
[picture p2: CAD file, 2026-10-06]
enclosure/dialback-zero-base.stl
149.0 x 86.0 x 24.9

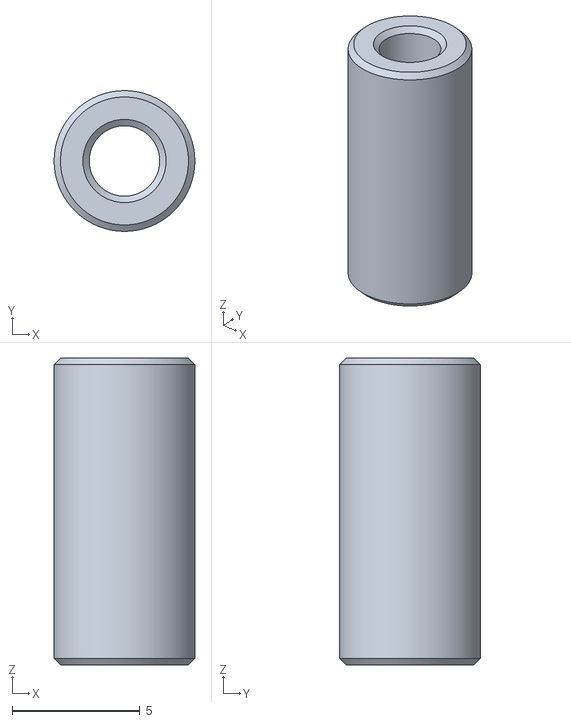
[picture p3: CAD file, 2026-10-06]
enclosure/pi-spacer-12mm.stl
5.50 x 5.50 x 12.0

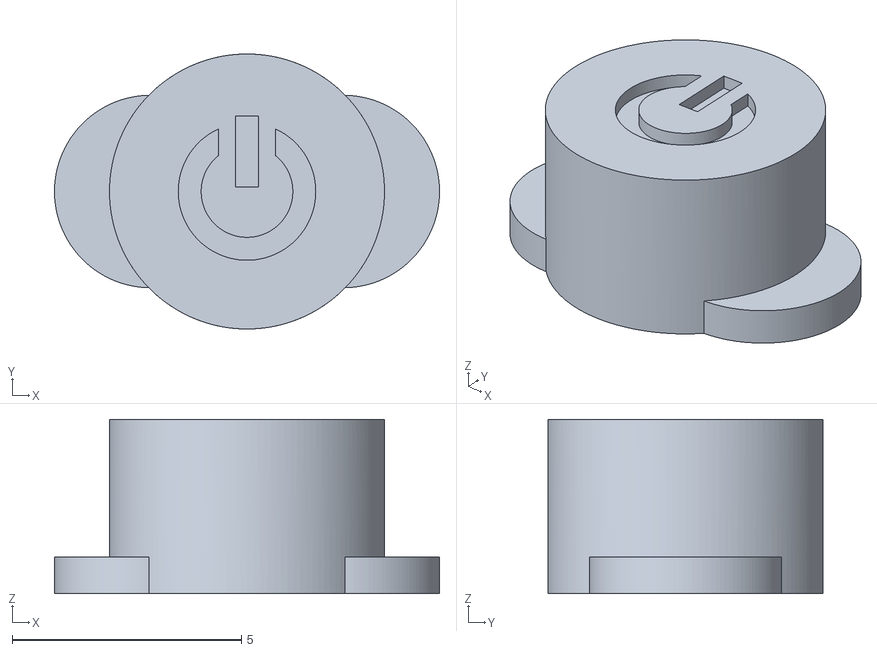
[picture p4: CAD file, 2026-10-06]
enclosure/power-button-cap.stl
8.40 x 6.00 x 3.80

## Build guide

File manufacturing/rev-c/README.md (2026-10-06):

# Rev C manufacturing files

| File | Use |
| --- | --- |
| [Gerbers](dialback-zero-rev-c-jlcpcb-gerbers.zip) | PCB layers and drill files |
| [Factory BOM](dialback-zero-rev-c-jlcpcb-bom.csv) | 41 rows covering 89 factory-installed components |
| [CPL](dialback-zero-rev-c-jlcpcb-cpl.csv) | Matching top-side component positions and rotations |
| [Complete BOM](design-bom.csv) | All 104 component references |
| [Manifest](manifest.json) | File checksums and design identity |

Upload the Gerber ZIP for PCB fabrication. For JLCPCB assembly, also upload the
factory BOM and CPL together. The CPL already includes the supplier-specific
rotations and USB-C connector offset; check the placement preview before ordering.

The 15 remaining components are soldered by hand after factory assembly.
See the [parts list](../../docs/self-solder-parts.md) and
[assembly guide](../../docs/assembly.md). J1 is the only underside component.

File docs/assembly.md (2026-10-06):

# Assemble a Rev C board

The factory fits the surface-mount parts, including USB-C J4. Add the
[15 hand-soldered parts](self-solder-parts.md):

1. Check the board against the [Rev C manufacturing package](../manufacturing/rev-c/README.md).
2. Fit the 2 × 20 Pi socket J1 **underneath** the carrier. Fit all other parts
   on top. Follow the LED cathode and C17 polarity markings. LS1 is an 8-ohm
   magnetic speaker, not a piezo sounder.
3. Attach the Pi with its top male header engaging J1 and 12 mm spacers.
   Check full insertion and clearance before applying power.
4. Test outside the enclosure. Supply **5 V through the carrier's USB-C**.
   Do power the Pi through its own power connector.

Leave the MUTE header open for sound. An optional 2.54 mm jumper mutes the speaker.

## Check before closing the case

Follow [first boot](setup.md), then check:

- Switched 5 V and local 3.3 V rails; check for overheating.
- `AT` replies `OK`, with and without an upstream network connection.
- PPP connects, resolves a hostname, transfers data and hangs up.
- A BBS connection transfers data and hangs up.
- PWR, MR, NET, SD, RD, CD, OH and AA lights work.
- `ATM1` enables dialing sounds; `ATM0` silences them.
- Settings work through both the vintage browser and serial terminal.
- A short POWER press shuts Linux down before cutting power; another press
  boots it. A software reboot also works. A long press forces power off.

Fit the [enclosure](../enclosure/README.md), checking Pi, header and connector
clearance before fastening it. Use a short POWER press for normal shutdown.

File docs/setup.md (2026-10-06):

# First boot

## Prepare the card

Follow [the image guide](../image/README.md) to download or build an image.
Write the `.img.xz` with Raspberry Pi Imager 2.x and set your user account,
network and locale. Supported boards: Pi Zero, Zero W/WH and Zero 2 W.

Insert the card, connect Ethernet or configure Wi-Fi on a W model, and power
only the carrier's USB-C input.

## Connect a computer

1. Use a straight-through RS-232 cable: **38400 baud, 8N1, flow control off**.
2. Type `AT` and Enter; expect `OK`. Use `AT$CONFIG` while disconnected for settings.
3. Dial **2242525** with your PPP/dial-up client, using automatic IP and DNS.
4. Open **http://172.16.0.1/** for settings. Restart the device after saving.

The Internet PPP addresses are `172.16.0.1` (Pi) and `172.16.0.2` (computer).
For a TCP BBS, dial its hostname and port, for example `ATDTbbs.example:23`.
If typed characters appear twice, disable local echo in the terminal.

`ATM1` enables dialing sounds; `ATM0` disables them. Set speaker volume in
settings and leave the MUTE jumper open. Complete the
[assembly checks](assembly.md#check-before-closing-the-case) before closing the case.

## Private network

Set up the [server](../server/README.md), then copy its `pi-hub.json` to the Pi's
home directory. Keep this file private: it contains the Pi's WireGuard key.
For an older installation, [update the runtime](../software/README.md#update) first.

On the Pi, import the profile. Disconnect any active call before restarting:

```sh
sudo python3 /usr/local/lib/dialback-zero/hub_setup.py --profile ~/pi-hub.json
sudo systemctl restart dialback-zero.target
```

Use `--replace` only to replace a different existing profile; keep a backup.
Create a second dial-up connection for **777**, using the same serial settings
and automatic IP and DNS. Open **http://retro.net/** for the home page and
**http://files.retro.net/** for downloads.

Private PPP uses `172.16.77.1` (Pi/settings) and `172.16.77.2` (computer).
Open `http://172.16.77.1/` for settings and its HTTP/DNS connection test.
Private DNS is `10.77.0.1`; `http://10.77.0.1/` also opens the server directly.
The home LAN must not overlap `10.77.0.0/24` or either PPP address pair.
Dial **2242525** again for ordinary Internet access.

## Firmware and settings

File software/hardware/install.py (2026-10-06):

#!/usr/bin/env python3
"""Install Dialback Zero carrier settings on a Pi Zero or a mounted Pi OS image.

No services are started/stopped and no shutdown/reboot is requested. Settings
take full effect at the next boot. Existing changed files are backed up.
"""

import argparse
from datetime import datetime, timezone
import json
import os
from pathlib import Path
import re
import shutil
import tempfile

SOURCE = Path(__file__).resolve().parent
START = "# BEGIN Dialback Zero managed include"
END = "# END Dialback Zero managed include"
INCLUDE = f"{START}\n[all]\ninclude dialback-zero.txt\n{END}\n"
OVERLAYS = {"audremap", "gpio-shutdown", "gpio-poweroff", "pwm", "pwm-2chan"}
MASKS = ("hciuart.service", "serial-getty@serial0.service", "serial-getty@ttyAMA0.service")


def managed_config(text):
    if text.count(START) != text.count(END) or text.count(START) > 1:
        raise ValueError("Malformed/duplicate Dialback Zero config markers")
    clean = re.sub(re.escape(START) + r".*?" + re.escape(END) + r"\n?", "", text, flags=re.S)
    return clean.rstrip() + "\n\n" + INCLUDE


def inside(root, relative):
    path = root / relative
    # Offline images must not follow an absolute symlink into the host filesystem.
    if not path.parent.resolve().is_relative_to(root):
        raise ValueError(f"Path escapes the selected root: {path}")
    if path.is_symlink():
        raise ValueError(f"Refusing to replace a symlink configuration file: {path}")
    return path


def check_boot_includes(boot, main_text, ethernet=False):
    seen = set()

    def scan(text, name):
        text = re.sub(re.escape(START) + r".*?" + re.escape(END), "", text, flags=re.S)
        for number, raw in enumerate(text.splitlines(), 1):
            line = raw.split("#", 1)[0].strip()
            if line.startswith("dtoverlay="):
                overlay = line.split("=", 1)[1].split(",", 1)[0]
                if overlay in OVERLAYS or (ethernet and (
                    overlay in {"w5500", "w5100", "enc28j60", "w1-gpio", "w1-gpio-pullup"}
                    or overlay.startswith("spi0")
                )):
                    raise ValueError(f"Conflicting overlay in {name}:{number}; remove the old manual entry first: {line}")
            if line.startswith("gpio="):
                pin_spec = line.split("=", 2)[1]
                pins = set()
                for item in pin_spec.split(","):
                    ends = item.strip().split("-")
                    if all(end.isdigit() for end in ends) and len(ends) in (1, 2):
                        pins.update(range(int(ends[0]), int(ends[-1]) + 1))
                if pins & {3, 26}:
                    raise ValueError(f"Conflicting power GPIO setting in {name}:{number}: {line}")
                if ethernet and pins & {4, 8, 9, 10, 11}:
                    raise ValueError(f"Conflicting Ethernet GPIO setting in {name}:{number}: {line}")
            if line.startswith("include "):
                include = line.split(None, 1)[1].strip()
                if include == "dialback-zero.txt":
                    raise ValueError("Unmanaged include dialback-zero.txt already exists; remove it before installing")
                path = (boot / include).resolve()
                if not path.is_relative_to(boot.resolve()):
                    raise ValueError(f"Boot include escapes boot directory: {include}")
                if path.exists() and path not in seen:
                    seen.add(path)
                    scan(path.read_text(), str(path))

    scan(main_text, "config.txt")


def build_plan(root, hardware="rev-b-ltc2954", include_runtime=True):
    if hardware not in {"rev-b-ltc2954", "rev-c-ethernet"}:
        raise ValueError(f"Unsupported hardware: {hardware}")
    ethernet = hardware == "rev-c-ethernet"
    boot = root / "boot/firmware"
    if not (boot / "config.txt").is_file():
        boot = root / "boot"
    config = inside(root, str((boot / "config.txt").relative_to(root)))
    cmdline = inside(root, str((boot / "cmdline.txt").relative_to(root)))
    if not config.is_file() or not cmdline.is_file():
        raise ValueError("Mount the Pi OS root and boot partitions; config.txt and cmdline.txt are required")
    required = ["audremap", "gpio-shutdown", "gpio-poweroff", "disable-bt"]
    if ethernet:
        required.append("w5500")
        if not any((root / p).is_file() for p in (
            "usr/lib/systemd/system/NetworkManager.service",
            "lib/systemd/system/NetworkManager.service",
        )):
            raise ValueError("Rev C Ethernet requires Raspberry Pi OS with NetworkManager installed")
    for overlay in required:
        if not (boot / "overlays" / f"{overlay}.dtbo").is_file():
            raise ValueError(f"Missing {overlay}.dtbo in the target boot partition")
    if not (root / "etc/systemd").is_dir():
        raise ValueError("Target must be a systemd-based Raspberry Pi OS image")
    text = config.read_text()
    check_boot_includes(boot, text, ethernet)
    args = cmdline.read_text().strip().splitlines()
    if len(args) != 1:
        raise ValueError("cmdline.txt must contain exactly one non-empty line")
    tokens = [t for t in args[0].split() if not re.match(r"console=(serial0|ttyAMA0)(,|$)", t)]
    boot_settings = (SOURCE / "config.txt.example").read_text()
    if ethernet:
        boot_settings += "\n" + (SOURCE / "ethernet-config.txt.example").read_text()
    plan = {
        config: managed_config(text),
        cmdline: " ".join(tokens) + "\n",
        inside(root, str((boot / "dialback-zero.txt").relative_to(root))): boot_settings,
        inside(root, "etc/asound.conf"): (SOURCE / "asound.conf").read_text(),
        inside(root, "etc/systemd/logind.conf.d/90-dialback-zero.conf"): (SOURCE / "logind.conf").read_text(),
        inside(root, "etc/udev/rules.d/70-dialback-zero-power.rules"): (SOURCE / "power-switch.rules").read_text(),
        inside(root, "usr/local/lib/dialback-zero-recovery.py"): (SOURCE.parent / "update_recovery.py").read_text(),
        inside(root, "etc/systemd/system/dialback-zero-update-recovery.service"):
            (SOURCE.parent / "systemd/dialback-zero-update-recovery.service").read_text(),
    }
    if ethernet:
        for target, source in {
            "usr/local/lib/dialback-zero/prepare-ethernet.py": "prepare-ethernet.py",
            "usr/local/lib/dialback-zero/ethernet.nmconnection.example": "ethernet.nmconnection.example",
            "etc/systemd/system/dialback-zero-ethernet.service": "ethernet.service",
            "etc/systemd/system/NetworkManager.service.d/90-dialback-zero-ethernet.conf": "ethernet-nm.conf",
        }.items():
            # The full appliance installer places these helpers in its immutable
            # release tree; direct hardware-only installs retain their old path.
            if not include_runtime and target.startswith("usr/local/lib/dialback-zero/"):
                continue
            plan[inside(root, target)] = (SOURCE / source).read_text()
    mask_paths = []
    for unit in MASKS:
        path = root / "etc/systemd/system" / unit
        if not path.parent.resolve().is_relative_to(root):
            raise ValueError(f"Service mask escapes the selected root: {path}")
        mask_paths.append(path)
    return plan, mask_paths


def install(root, plan, masks, dry_run):
    changed = [(p, data) for p, data in plan.items() if not p.exists() or p.read_text() != data]
    changed_masks = [p for p in masks if not p.is_symlink() or os.readlink(p) != "/dev/null"]
    for path, _ in changed:
        print(f"WRITE {path}")
    for path in changed_masks:
        print(f"MASK  {path}")
    if dry_run or not (changed or changed_masks):
        print("Dry run; nothing changed." if dry_run else "Already installed; nothing changed.")
        return
    stamp = datetime.now(timezone.utc).strftime("%Y%m%dT%H%M%S.%fZ")
    backup = inside(root, f"var/lib/dialback-zero/backups/{stamp}/manifest.json").parent
    backup.mkdir(parents=True)
    manifest = []
    for path in [p for p, _ in changed] + changed_masks:
        relative = path.relative_to(root)
        exists = path.exists() or path.is_symlink()
        manifest.append({"path": str(relative), "existed": exists})
        if exists:
            saved = backup / relative
            saved.parent.mkdir(parents=True, exist_ok=True)
            shutil.copy2(path, saved, follow_symlinks=False)
    (backup / "manifest.json").write_text(json.dumps(manifest, indent=2) + "\n")
    for path, data in changed:
        path.parent.mkdir(parents=True, exist_ok=True)
        with tempfile.NamedTemporaryFile(mode="w", dir=path.parent, delete=False) as tmp:
            tmp.write(data)
            temp_path = Path(tmp.name)
        try:
            temp_path.chmod(0o644)
            temp_path.replace(path)
        finally:
            temp_path.unlink(missing_ok=True)
    for path in changed_masks:
        path.parent.mkdir(parents=True, exist_ok=True)
        path.unlink(missing_ok=True)
        path.symlink_to("/dev/null")
    print(f"Backups: {backup}")
    print("Installed. No services restarted and no reboot requested. Reboot the target Pi to activate.")


def main():
    parser = argparse.ArgumentParser(description=__doc__)
    parser.add_argument("--root", type=Path, default=Path("/"), help="Mounted Pi OS root (default: this Pi)")
    parser.add_argument("--hardware", required=True, choices=["rev-b-ltc2954", "rev-c-ethernet"], help="Mono carrier with LTC2954-1 power control; Rev C adds W5500 Ethernet")
    parser.add_argument("--dry-run", action="store_true")
    args = parser.parse_args()
    try:
        root = args.root.resolve(strict=True)
        if root == Path("/"):
            model = Path("/proc/device-tree/model")
            if not model.exists() or "Raspberry Pi Zero" not in model.read_text():
                raise ValueError("Live installation is restricted to Raspberry Pi Zero models; use --root for a mounted image")
            if not args.dry_run and os.geteuid() != 0:
                raise ValueError("Run the live installation with sudo")
        plan, masks = build_plan(root, args.hardware)
        install(root, plan, masks, args.dry_run)
    except (ValueError, OSError) as exc:
        parser.exit(1, f"Installation refused: {exc}\n")


if __name__ == "__main__":
    main()

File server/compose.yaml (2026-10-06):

services:
  wireguard:
    build:
      context: .
      target: wireguard
    restart: unless-stopped
    cap_drop: [ALL]
    cap_add: [NET_ADMIN]
    security_opt: [no-new-privileges:true]
    read_only: true
    tmpfs:
      - /run:mode=0700
    environment:
      WG_PRIVATE_KEY: ${WG_PRIVATE_KEY:-}
      WG_PEER_PUBLIC_KEY: ${WG_PEER_PUBLIC_KEY:?Run server/setup.py and import server.env}
    ports:
      - "${DBZ_BIND_IP:?Set the server LAN IPv4 address}:${DBZ_WG_PORT:-51820}:51820/udp"
    sysctls:
      net.ipv4.ip_forward: "0"
      net.ipv4.ip_unprivileged_port_start: "0"
      net.ipv6.conf.all.disable_ipv6: "1"
    healthcheck:
      test: [CMD-SHELL, "wg show wg0 public-key >/dev/null && ip -4 address show dev wg0 | grep -q '10.77.0.1/24'"]
      interval: 10s
      timeout: 3s
      retries: 3

  http:
    build:
      context: .
      target: http
    restart: unless-stopped
    network_mode: service:wireguard
    depends_on:
      wireguard:
        condition: service_healthy
        restart: true
      sites:
        condition: service_healthy
    cap_drop: [ALL]
    security_opt: [no-new-privileges:true]
    read_only: true
    tmpfs:
      - /tmp:uid=10001,gid=10001,mode=0700
    volumes:
      - downloads:/srv/downloads:ro
    healthcheck:
      test: [CMD-SHELL, "wget -q -O /dev/null http://10.77.0.1/"]
      interval: 30s
      timeout: 3s
      retries: 3

  dns:
    build:
      context: .
      target: dns
    restart: unless-stopped
    network_mode: service:wireguard
    depends_on:
      wireguard:
        condition: service_healthy
        restart: true
    cap_drop: [ALL]
    security_opt: [no-new-privileges:true]
    read_only: true
    volumes:
      - site-dns:/srv/site-dns:ro
    healthcheck:
      test: [CMD-SHELL, "nslookup www.retro.home.arpa 10.77.0.1 >/dev/null 2>&1"]
      interval: 30s
      timeout: 3s
      retries: 3

  sites:
    build:
      context: .
      target: sites
    restart: unless-stopped
    network_mode: service:wireguard
    depends_on:
      wireguard:
        condition: service_healthy
        restart: true
    cap_drop: [ALL]
    security_opt: [no-new-privileges:true]
    read_only: true
    environment:
      DBZ_DATA_DIR: /data
      DBZ_DNS_DIR: /dns
      DBZ_MEMBERS_HOST: members.retro.net
    tmpfs:
      - /tmp:uid=10001,gid=10001,mode=0700
    volumes:
      - sites:/data
      - site-dns:/dns
    healthcheck:
      test: [CMD-SHELL, "wget -q -O /dev/null http://127.0.0.1:8080/healthz"]
      interval: 10s
      timeout: 3s
      retries: 6

  ftp:
    build:
      context: .
      target: sites
    entrypoint: [python3, /app/ftp.py]
    restart: unless-stopped
    network_mode: service:wireguard
    depends_on:
      wireguard:
        condition: service_healthy
        restart: true
      sites:
        condition: service_healthy
    cap_drop: [ALL]
    security_opt: [no-new-privileges:true]
    read_only: true
    environment:
      DBZ_DATA_DIR: /data
      DBZ_DNS_DIR: /dns
      DBZ_FTP_BIND: 10.77.0.1
      DBZ_FTP_PORT: "21"
      DBZ_FTP_PASSIVE_ADDRESS: 10.77.0.1
    tmpfs:
      - /tmp:uid=10001,gid=10001,mode=0700
    volumes:
      - sites:/data
      - site-dns:/dns:ro
    healthcheck:
      test: [CMD, python3, -c, "import socket; s=socket.create_connection(('10.77.0.1',21),3); assert s.recv(256).startswith(b'220'); s.close()"]
      interval: 30s
      timeout: 5s
      retries: 3

volumes:
  downloads:
  sites:
  site-dns:

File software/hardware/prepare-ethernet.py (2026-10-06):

#!/usr/bin/env python3
"""Prepare one W5500 NetworkManager profile before networking starts on a Pi.

No network commands run here. Existing IP/DNS/priority settings are preserved;
only the locally administered MAC follows the Pi's serial number on each boot.
"""

import configparser
import hashlib
import io
from pathlib import Path
import re
import tempfile

PROFILE = "etc/NetworkManager/system-connections/dialback-zero-w5500.nmconnection"
PROFILE_UUID = "553e90a5-f31d-52a1-a72d-8b514d57b470"
TEMPLATE = "usr/local/lib/dialback-zero/ethernet.nmconnection.example"


def mac_from_serial(serial):
    serial = serial.rstrip("\0\n").lower()
    if not re.fullmatch(r"[0-9a-f]{16}", serial) or int(serial, 16) == 0:
        raise ValueError("A valid, non-zero Pi serial number is required; no shared fallback MAC is allowed")
    octets = bytearray(hashlib.sha256(("Dialback Zero W5500 v1:" + serial).encode("ascii")).digest()[:6])
    octets[0] = (octets[0] & 0xfc) | 0x02  # locally administered, unicast
    return ":".join(f"{octet:02x}" for octet in octets)


def profile_text(existing, template, mac):
    text = existing if existing is not None else template.replace("@MAC@", mac)
    profile = configparser.ConfigParser(interpolation=None, delimiters=("=",), comment_prefixes=("#",))
    profile.read_string(text)
    if profile.get("connection", "uuid", fallback="") != PROFILE_UUID:
        raise ValueError("The Dialback Zero profile path contains an unrelated profile")
    if profile.get("match", "driver", fallback="").rstrip(";") != "w5100":
        raise ValueError("The Dialback Zero profile must match only the w5100 driver")
    # NetworkManager can use either the long section name or its keyfile alias.
    section = "802-3-ethernet" if profile.has_section("802-3-ethernet") else "ethernet"
    if not profile.has_section(section):
        profile.add_section(section)
    if profile.get(section, "cloned-mac-address", fallback="") == mac:
        return text
    profile.set(section, "cloned-mac-address", mac)
    output = io.StringIO()
    profile.write(output, space_around_delimiters=False)
    return output.getvalue()


def prepare(root):
    root = root.resolve(strict=True)
    model = (root / "proc/device-tree/model").read_text().rstrip("\0")
    if not model.startswith("Raspberry Pi Zero"):
        raise ValueError("Ethernet identity preparation is restricted to Raspberry Pi Zero models")
    mac = mac_from_serial((root / "proc/device-tree/serial-number").read_text())
    target = root / PROFILE
    if target.is_symlink() or not target.parent.resolve().is_relative_to(root):
        raise ValueError("Refusing a symlink profile or a path outside the selected root")
    existing = target.read_text() if target.exists() else None
    updated = profile_text(existing, (root / TEMPLATE).read_text(), mac)
    if existing != updated:
        target.parent.mkdir(parents=True, exist_ok=True)
        with tempfile.NamedTemporaryFile(mode="w", dir=target.parent, delete=False) as temporary:
            temporary.write(updated)
            temporary_path = Path(temporary.name)
        try:
            temporary_path.chmod(0o600)
            temporary_path.replace(target)
        finally:
            temporary_path.unlink(missing_ok=True)
    target.chmod(0o600)
    return mac


if __name__ == "__main__":
    try:
        print("Dialback Zero Ethernet MAC: " + prepare(Path("/")))
    except (OSError, ValueError, configparser.Error) as exc:
        raise SystemExit(f"Ethernet profile preparation failed: {exc}") from exc
